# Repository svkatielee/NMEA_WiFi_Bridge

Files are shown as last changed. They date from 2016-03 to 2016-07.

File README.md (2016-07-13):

# NMEA_WiFi_Bridge
An ESP8266-01 WiFi module to read NMEA serial data and UDP broadcast it to multiple openCPN instances as a Bridge.

<b>Update: This code has been tested with Arduino IDE rev 1.6.9 and ESP8266 addin of 2.1.0. Newer compilers fail.</b>

<b>Warning: A work in progress</b>

I want to be able to run openCPN on both a laptop and a tablet at the same time. I would like the laptop down below deck, safe from the rain and salt water spray. I would like to have a mostly waterproof tablet in the cockpit to monitor progress. And I would like to be able to quickly check the ship's status from the captain's berth when off watch, maybe on a smart phone.

The plan is to implement a device to read the serial data from all the boat instruments and send that data to openCPN over a WiFI link so there are no physical wires attached. It will broadcast the data with UDP so that multiple devices can read the data at the same time.

The ESP8266 ESP-01 was chosen because it was on hand and it has adequate I/O for this project.

The rs-232 input signal voltage should work with -12 to +12 volts. It was tested with a Garmin 72H which puts out -5 to +5.

<h3>Setup</h3>
Connect power and input signal rs-232 line with ground.
Press and hold config button, press reset, 
     continue to hold config until the LED stays lit.
Connect to the AP "NMEA WiFi Bridge" with a system/phone/etc.
Connect your brower to 10.1.1.1 with password in code "nmeawifi".`
Configure the form for your network and click the "configure" button.
Verify the results page.
Press reset or cycle power for the module to connect to your network.

To verify it is working, there is a status page on the address on the NMEA WiFi Bridge. Type this address into your browser.

<h3>Credits</h3>
The ESP was programmed with the Arduino IDE for ESP 1.6.5 and the board manager version 1.6.5-947-g39819f0.

Also uses the pfodWebWiFiConfig and adapted schematic from http://www.forward.com.au/pfod/CheapWifiShield/ESP2866_01_WiFi_Shield/ESP8266_01_WiFi_Shield_R1/index.html for the dynamic web config of the ESP.

I used the version 1.9 of the library pfodWifiConfig.zip which is now included as Doc/pfodWifiConfig.zip

<quote>
/**
 *  Cheap and Simple Wifi Shield for Arduino and other micros
 * http://www.forward.com.au/pfod/CheapWifiSheild/index.html
 *
 * (c)2015 Forward Computing and Control Pty. Ltd.
 * This code may be freely used for both private and commerical use.
 * Provide this copyright is maintained.
 */
</quote>

Follow his instructions for setting up the library from above. 
(Also copied here from http://www.forward.com.au/ for the verison I used)

---------------------------
<quote>
<h4>Programming the WiFi Shield</h4>

The WiFi Shield needs to be programmed once, only, and never again, with the web page configuration and the Serial to WiFi Bridge code.

To program the shield follow the instructions given on https://github.com/esp8266/Arduino under Installing With Boards Manager. When opening the Boards Manager from the Tools → Board menu and select Type Contributed and install the esp8266 platform. This project was compiled using the ESP8266 version 1.6.4-673-g8cd3697. Later versions well be better but may have their own bugs as the platform is evolving rapidly.

Close and re-open the Arduino IDE and you can now select “Generic ESP8266 Module” from Tools → Board menu.

You also need to install the latest version of pfodWifiConfig.zip which handles the storing and retrieval of the settings in EEPROM

a) Download this pfodWifiConfig.zip file to your computer, move it to your desktop or some other folder you can easily find<br>
b) Then use Arduino 1.6.5 IDE menu option Sketch → Import Library → Add Library to install it.<br>
(If Arduino does not let you install it because the library already exists then find and delete the older pfodWifiConfig folder and then import this one)<br>
c) Stop and restart the Arduino IDE and under File->Examples you should now see pfodWifiConfig.<br>
</quote>
---------------------------

Also borrowed from http://www.scienceprog.com/alternatives-of-max232-in-low-budget-projects/ for the rs-232 to ttl translation for the input pin.

And last but not least some programming concepts from https://github.com/wa0uwh/ERB-EspWebServer.

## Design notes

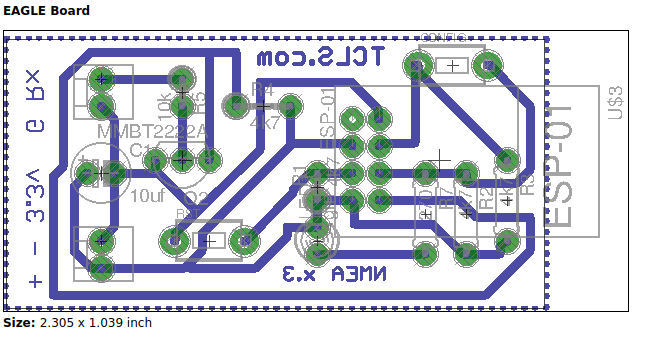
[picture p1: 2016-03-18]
eagle/NMEA_WiFi_Bridge_brd.png

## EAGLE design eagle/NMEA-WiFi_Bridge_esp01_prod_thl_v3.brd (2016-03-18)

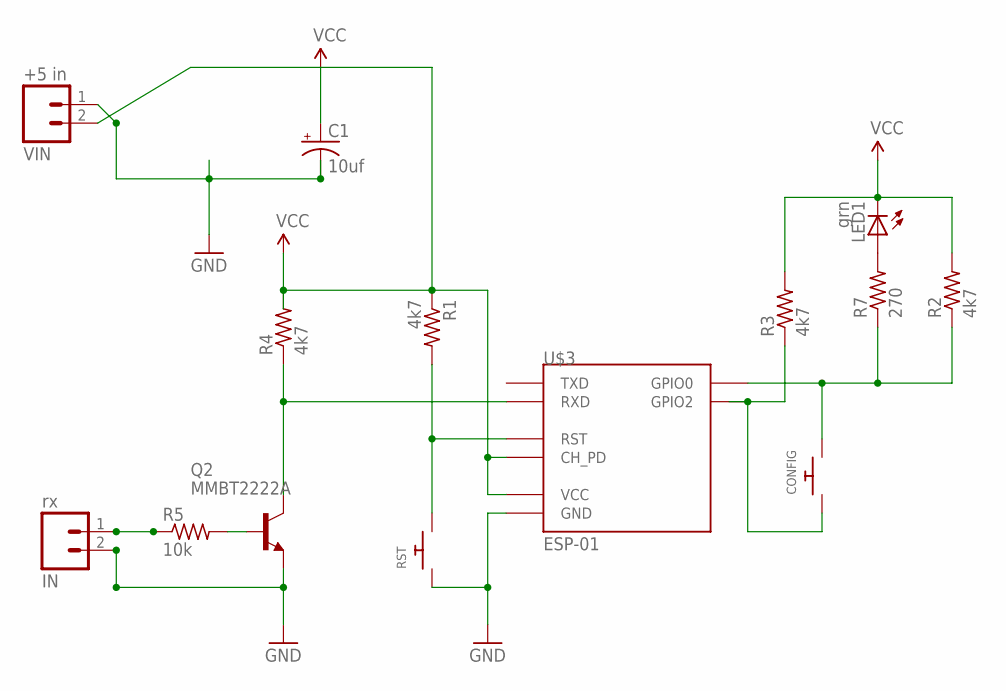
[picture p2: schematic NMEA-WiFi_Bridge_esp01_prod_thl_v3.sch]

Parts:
C1: 10uf; E2,5-6
CONFIG: SWITCH_PUSHBUTTONEVQ-PE; TACT_PANA-EVQ
IN: rx; MOLEX-1X2
LED1: grn; LED3MM
Q2: MMBT2222A; TO92-CBE
R1: 4k7; 0207/2V
R2, R3: 4k7; 0207/7
R4: 4k7; 0207/5V
R5: 10k; 0207/2V
R7: 270; 0207/7
RST: SWITCH_PUSHBUTTONEVQ-PE; TACT_PANA-EVQ
U$3: ESP-01
VIN: +5 in; MOLEX-1X2

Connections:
GND: C1.-, IN.2, Q2.E, RST.P$1, U$3.GND, VIN.1
GPIO0: CONFIG.P$2, R2.1, R7.1, U$3.GPIO0
unnamed: CONFIG.P$1, R3.1, U$3.GPIO2
unnamed: Q2.B, R5.2
unnamed: IN.1, R5.1
unnamed: LED1.A, R7.2
RST: R1.2, RST.P$2, U$3.RST
RX: Q2.C, R4.1, U$3.RX (RXD)
VCC: C1.+, LED1.K (C), R1.1, R2.2, R3.2, R4.2, U$3.CH_PD, U$3.VCC, VIN.2

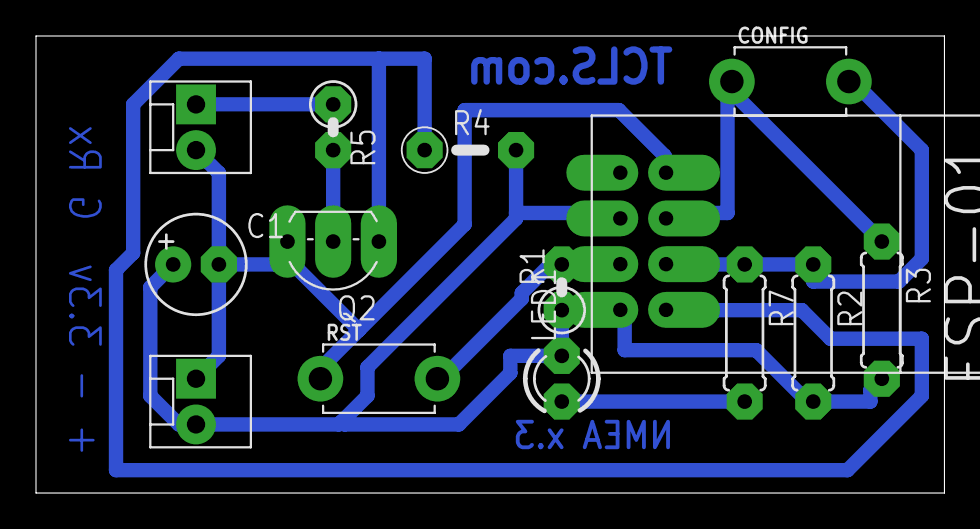
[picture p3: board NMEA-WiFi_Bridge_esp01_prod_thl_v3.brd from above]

Board: 2 copper layers, 50.5 x 25.4 mm, 14 parts (0 on the bottom side), 9 nets.

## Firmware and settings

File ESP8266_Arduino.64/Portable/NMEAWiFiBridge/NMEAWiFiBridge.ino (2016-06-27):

/*

   Copyright (c) Sept 8-2015. @ Larry Littlefield TCLS.com kb7kmo.blogspot.com
   GPL v2 
   https://github.com/svkatielee/

   
   Serial Wifi Bridge
   
   The desired purpose of this program is to take an rs-232 data stream and send it via 
   a UDP network protocol via WiFi to openCPN eleminating any data wires to the navagation system.
   Planning for a boat with a single network, the UDP is sent to the broadcast address
   of your network. ie.: 192.168.xx.255:10110

   Configure multiple openCPN systems connections, each with: network:UDP:localhost(0.0.0.0):10110 
   my testing with no checksum, no filtering at 4800 baud input
   
   It is written for an ESP8266-01 on a board similar to:
   http://www.forward.com.au/pfod/CheapWifiShield/ESP2866_01_WiFi_Shield/ESP8266_01_WiFi_Shield_R1/index.html

   It expects a NMEA 0183 rs-232 data stream input on the in pin connected to RX 
   via a 2N2222 to convert and invert -3.3v-+3.3v into 0-3.3v
   as seen: http://www.scienceprog.com/alternatives-of-max232-in-low-budget-projects/

   And some code and concepts borrowed from a friend, https://github.com/wa0uwh/ERB-EspWebServer

*/

 /**
 *  Cheap and Simple Wifi Shield for Arduino and other micros
 * http://www.forward.com.au/pfod/CheapWifiSheild/index.html
 *
 * (c)2015 Forward Computing and Control Pty. Ltd.
 * This code may be freely used for both private and commerical use.
 * Provide this copyright is maintained.
 */
 
#include <EEPROM.h>
#include <ESP8266WiFi.h>
#include <WiFiUdp.h>
#include <WiFiClient.h>
#include <ESP8266WebServer.h>
#include "pfodWifiConfig.h"

extern "C" {
    #include "user_interface.h"
    uint16 readvdd33(void);
}

#define DEBUG
#define Rev "LGL.00.06"
// ERB - Force format stings and string constants into FLASH Memory
    #define sF(x) (String) F(x)                // Used as an F() is being used as the first Element of a Multi-Element Expression
    #define FMT(x) strcpy_P(gFmtBuf, PSTR(x))  // Used with printf() for the format string
    // USE WITH CAUTION !
char gFmtBuf[64+2];



WiFiServer server(80);
WiFiClient client;
WiFiUDP udp;
pfodWifiConfig pfodWifiConfig;

// =============== start of pfodWifiWebConfig settings ==============
//#define pfodWifiWebConfigAP "WiFiBridge"
//#define pfodWifiWebConfigPASSWORD "lgl"
String pfodWifiWebConfigAP = "NMEA WiFi Bridge";
String pfodWifiWebConfigPASSWORD = "nmeawifi";


// note pfodSecurity uses 19 bytes of eeprom usually starting from 0 so
// start the eeprom address from 20 for configureWifiConfig
int eepromAddress = 20;
int wifiSetup_pin = 2; // name the input pin for setup mode detection GPIO2 on most ESP8266 boards
// =============== end of pfodWifiWebConfig settings ==============

// On ESP8266-01 and Adafruit HAZZAH ESP8266, connect LED + 270ohm resistor from D0 (GPIO0) to +3V3 to indicate when in config mode

char ssid[pfodWifiConfig::MAX_SSID_LEN + 1]; // allow for null  field 1
char security[pfodWifiConfig::MAX_SECURITY_LEN + 1]; // field 2
char password[pfodWifiConfig::MAX_PASSWORD_LEN + 1]; // field 3
char portNo[pfodWifiConfig::MAX_PORTNO_STR_LEN + 1]; // field 4
char staticIP[pfodWifiConfig::MAX_STATICIP_LEN + 1]; // field 5 use dhcp if empty
char hostName[pfodWifiConfig::MAX_HOSTNAME_LEN + 1]; // field 6
char userName[pfodWifiConfig::MAX_USERNAME_LEN + 1]; // field 7
char userPw[pfodWifiConfig::MAX_USER_PASSWORD_LEN + 1]; // field 8


uint16_t ipSources = pfodFeatures::DHCP | pfodFeatures::STATIC_IP; // bit or these together pfodFeatures::DHCP|pfodFeatures::STATIC_IP if both are available
uint16_t securityFeatures = pfodFeatures::WPA | pfodFeatures::WPA2; // bit or these together e.g. pfodFeatures::OPEN | pfodFeatures::WPA

ESP8266WebServer webserver ( 80 );  // this just sets portNo nothing else happens until begin() is called

String msg;
byte inConfigMode = 0; // false

IPAddress opencpnServer;          // openCPN system server network broadcast
unsigned int localPort = 2948;    // local port to listen for UDP packets only needed for startup
unsigned int cpnPort;             // remote port to send UDP packets
unsigned int baudRate;            // set serial baud for reading NMEA (stored as hostName)

const byte maxLen = 100;          // longest NMEA sentence
byte packetBuffer[maxLen];        // buffer for UDP communication
int len=0;                        // num chars in buffer
boolean stringComplete = false;   // whether the string is complete
#ifdef DEBUG 
int loop_count=1;                 // show progress in debug window
#endif
uint16_t udpPackSent=0;           // the number of UDP packets sent

char gTmpBuf[32+2];  // Generic Temp Buffer


//*******************************************************************
//===================================================================
void setup() {
  delay(2000); // skip the ESP8266 booting debug output
  pinMode(0,OUTPUT); // make GPIO0 an output
  digitalWrite(0,LOW); // make it LOW so it will ground GPIO2 if CONFIG_LINK is shorted out.
  // will turn led on, if any connected
  WiFi.mode(WIFI_STA);
  inConfigMode = 0; // non in config mode
  EEPROM.begin(512);
  
  Serial.begin(4800);
  delay(10);     // wait for serial to connect
  Serial.println();
  

pfodWifiConfig.setDebugStream(&Serial); // add this line if using DEBUG in pfodWifiConfig_ESP8266 library code

  //============ pfodWifiConfigV1 config in Access Point mode ====================
  // see if config button is pressed
  pinMode(wifiSetup_pin, INPUT_PULLUP);
  if (digitalRead(wifiSetup_pin) == LOW) {
    inConfigMode = 1; // in config mode
    WiFi.mode(WIFI_AP_STA);

#ifdef DEBUG
    Serial.println(F("Setting up Access Point for pfodWifiWebConfig"));
    Serial.print("AP: ");
    Serial.print(pfodWifiWebConfigAP);
    Serial.print(" Pw: ");
    Serial.println( pfodWifiWebConfigPASSWORD);
#endif
    // connect to temporary wifi network for setup
    // the features determine the format of the {set...} command
    setupAP(pfodWifiWebConfigAP, pfodWifiWebConfigPASSWORD);
    //   Need to reboot afterwards
    return; // skip rest of setup();
  }  
//============ end pfodWifiConfigV1 config ====================

  // else button was not pressed continue to load the stored network settings
  // make GPIO0 an input to turn led off when not in config mode, if any is connected
  pinMode(0,INPUT);

    // use these local vars
  char ssid[pfodWifiConfig::MAX_SSID_LEN + 1]; // allow for null
  char password[pfodWifiConfig::MAX_PASSWORD_LEN + 1];
  char staticIP[pfodWifiConfig::MAX_STATICIP_LEN + 1];
  char hostName[pfodWifiConfig::MAX_HOSTNAME_LEN + 1]; // use for Serial in baud rate
  uint16_t portNo = 0; // use for UDP portnumber cpnPort
  uint16_t security = 0;
  uint16_t ipSource = 0;
  byte mode = 0;

  pfodWifiConfig.loadNetworkConfigFromEEPROM(eepromAddress, &mode,
      (char*)ssid, pfodWifiConfig::MAX_SSID_LEN + 1, (char*)password,  pfodWifiConfig::MAX_PASSWORD_LEN + 1,
      &security, &portNo, &ipSource, (char*)staticIP,  pfodWifiConfig::MAX_STATICIP_LEN + 1);
  pfodWifiConfig.loadClientConfigFromEEPROM(eepromAddress, (char*)hostName, pfodWifiConfig::MAX_HOSTNAME_LEN, (char*)userName,
      pfodWifiConfig::MAX_USERNAME_LEN, (char*)userPw, pfodWifiConfig::MAX_USER_PASSWORD_LEN);

  // Use hostName for storing the baud rate for the NMEA input
  long longBaud = 0;
      pfodWifiConfig::parseLong((byte*)hostName, &longBaud);
      baudRate = (uint16_t)longBaud;

  Serial.begin(baudRate);
  server = WiFiServer(80);
  cpnPort = portNo;
  // Initialise wifi module
#ifdef DEBUG
  Serial.println(F("Normal boot"));
  Serial.print("Web server on port:"); Serial.println(80);
  Serial.println(F("Connecting to AP"));
  Serial.print("ssid '");
  Serial.print(ssid);
  Serial.println("'");
  Serial.print("password '");
  Serial.print(password);
  Serial.println("'");
#endif
  // Blink LED while trying to connect to WiFi
  pinMode(0,OUTPUT); // make GPIO0 an output
  int blink0 = 0;
  digitalWrite(0,blink0);
  WiFi.begin(ssid, password);
  while (WiFi.status() != WL_CONNECTED) {
    blink0 = ! blink0;
    digitalWrite(0,blink0);
    delay(500);
#ifdef DEBUG
    Serial.print(".");
#endif
  }
  digitalWrite(0, HIGH);  // finished using LED for connecting status
  pinMode(0,INPUT);
#ifdef DEBUG
  Serial.println();
  Serial.println(F("Connected!"));
#endif

  if (*staticIP != '\0') {
    // config static IP
    IPAddress ip(pfodWifiConfig::ipStrToNum(staticIP));
    IPAddress gateway(ip[0], ip[1], ip[2], 1); // set gatway to ... 1
#ifdef DEBUG
    Serial.print(F("Setting gateway to: "));
    Serial.println(gateway);
#endif
    IPAddress subnet(255, 255, 255, 0);
    WiFi.config(ip, gateway, subnet);
  } // else leave as DHCP


  // configure normal boot web server
  webserver.on ( "/", handleRootNormal );
  webserver.onNotFound ( handleNotFound );
  
  // Start listening for connections
#ifdef DEBUG
  Serial.println(F("Start Server"));
#endif
  webserver.begin();
  
  opencpnServer = WiFi.localIP(); // find my local IP address
  opencpnServer[3] = 255;         // Set last octet to 255 for Class C broadcast address of this subnet
  
#ifdef DEBUG
  Serial.println(F("Server Started"));
  // Print the IP address
  Serial.print(WiFi.localIP());
  Serial.print(':');
  Serial.println(80);
  Serial.println(F("Listening for connections..."));
  Serial.print("UDP send address: ");
  Serial.print(opencpnServer);
  Serial.print(":");
  Serial.println(cpnPort);
#endif

#ifdef DEBUG
  Serial.println("Starting UDP");
#endif
  udp.begin(localPort);
#ifdef DEBUG 
  Serial.print("Local port: ");
  Serial.println(udp.localPort());
#endif

#ifdef DEBUG
  Serial.println("+++"); // end of setup
#endif

}  // setup

//===================================================================
void setupAP( String ssid_wifi,  String password_wifi) {
  const char *aps = scanForAPs();
  delay(0);
#ifdef DEBUG
  Serial.println(aps);
#endif

  IPAddress local_ip = IPAddress(10, 1, 1, 1);
  IPAddress gateway_ip = IPAddress(10, 1, 1, 1);
  IPAddress subnet_ip = IPAddress(255, 255, 255, 0);

#ifdef DEBUG
  Serial.println(F("configure pfodWifiWebConfig"));
  Serial.print("AP: ");
  Serial.print(ssid_wifi);
  Serial.print(" Pw: ");
  Serial.println( password_wifi);
#endif

  WiFi.softAP(ssid_wifi.c_str(), password_wifi.c_str(), 6);
  //WiFi.softAP(ssid_wifi, 0, 6);

#ifdef DEBUG
  Serial.println();
  Serial.println(F("Access Point setup"));
#endif
  WiFi.softAPConfig(local_ip, gateway_ip, subnet_ip);

#ifdef DEBUG
  Serial.println("done");
  IPAddress myIP = WiFi.softAPIP();
  Serial.print(F("My address: "));
  Serial.println(myIP);
#endif


  msg = "<html>"
        "<head>"
        "<title>Serial to Wifi Bridge Setup</title>"
        "<meta charset=\"utf-8\" />"
        "<meta name=viewport content=\"width=device-width, initial-scale=1\">"
        "</head>"
        "<body>"
        "<h2>Serial to Wifi Bridge Setup</h2>"
        "<p>Use this form to configure this device to connect to your Wifi network and start as a Status server listening"
        " on port 80. Also configure the port that the NMEA data will be broadcast via UDP. And the baud rate for the NMEA data.</p>"
        "<p>Note: UDP packets will be sent to the broadcast IP of your class C network. ie.: nnn.nnn.nnn.255</P>"

        "<form class=\"form\" method=\"post\" action=\"/config\" >"
        "<p class=\"name\">"
        "<label for=\"name\">Network SSID</label><br>"
        "<input type=\"text\" name=\"1\" id=\"ssid\" placeholder=\"wifi network name\"  required "; // field 1

  if (*aps != '\0') {
    msg += " value=\"";
    msg += aps;
    msg += "\" ";
  }
  msg += " />"
         "</p> "
         "<p class=\"security\">"
         "<label for=\"security\">Security</label><br>"
         "<select name=\"2\" id=\"security\" required>" // field 2
         "<option value=\"WPA/WPA2\">WPA/WPA2</option>"
         "</select>"
         "</p>"
         "<p class=\"password\">"
         "<label for=\"password\">Password</label><br>"
         "<input type=\"text\" name=\"3\" id=\"password\" placeholder=\"wifi network password\" autocomplete=\"off\" required " // field 3
         "</p>"
         "<p class=\"static_ip\">"
         "<label for=\"static_ip\">Set the Static IP for this device</label><br>"
         "(If this field is empty, DHCP will be used to get an IP address)<br>"
         "<input type=\"text\" name=\"5\" id=\"static_ip\" placeholder=\"192.168.4.99\" "  // field 5
         " pattern=\"\\b(?:(?:25[0-5]|2[0-4][0-9]|[01]?[0-9][0-9]?)\\.){3}(?:25[0-5]|2[0-4][0-9]|[01]?[0-9][0-9]?)\\b\"/>"
         "</p>"
         "<p class=\"portNo\">"
         "<label for=\"portNo\">UDP broadcast port.</label><br>"
         "<input type=\"text\" name=\"4\" id=\"portNo\" placeholder=\"10110\" required"  // field 4
         " pattern=\"\\b([0-9]{1,4}|[1-5][0-9]{4}|6[0-4][0-9]{3}|65[0-4][0-9]{2}|655[0-2][0-9]|6553[0-5])\\b\" />"
         "</p>"
         "<p class=\"hostName\">"
         "<label for=\"hostName\">Baud rate for NMEA serial line.</label><br>"
        //"<input type=\"text\" name=\"6\" id=\"hostName\" placeholder=\"38400\" required"  // field 6
         "<select name=\"6\" id=\"hostName\" required>" // field 6 was hostName, using for Baud
         "<option value=\"4800\">4800</option>"
         "<option value=\"9600\">9600</option>"
         "<option value=\"38400\" selected>38400</option>"
         "<option value=\"115200\">115200</option>"
         "</select>"
         "</p>"
"<p class=\"submit\">"
         "<input type=\"submit\" value=\"Configure\"  />"
         "</p>"
         "</form>"
         "</body>"
         "</html>";


  delay(100);

  webserver.on ( "/", handleRoot );
  webserver.on ( "/config", handleConfig );
  webserver.onNotFound ( handleNotFound );
  webserver.begin();
#ifdef DEBUG
  Serial.println ( "HTTP webserver started" );
#endif
}  //end of setupAp



//********************************************************
// not really event driven serial input
void serialEvent() {
  while (Serial.available()) {
    // get the new byte:
    packetBuffer[len] = (char)Serial.read();
    // if the incoming character is a newline, set a flag
    // so the main loop can do something about it:
    if (packetBuffer[len] == '\n') {
      stringComplete = true;
    }
    yield();
    len++;
    if (len > maxLen) {    // if we missed the newline don't oveer run the buffer
      sendUDPpacket(opencpnServer); 
      len=0;
#ifdef DEBUG  
    Serial.println("maxLen exceeded");
#endif  
    }
  }
}


//********************************************************
// send the unidirectional UDP buffer to the specific address and preconfigured port
unsigned long sendUDPpacket(IPAddress& address)
{
#ifdef DEBUG 
  Serial.print("sending NTP packet=");
  Serial.println(len); 
#endif  
  udp.beginPacket(address, cpnPort); 
  udp.write(packetBuffer, len);
  udp.endPacket();
  udpPackSent++;
}



//*******************************************************************
//===================================================================
void loop() {
  if (inConfigMode) {
    webserver.handleClient();
    delay(0);
    return;
  } 
  delay(10);

#ifdef DEBUG 
  loop_count++;
  if ((loop_count % 10) == 0) Serial.print(".");
  if ((loop_count % 1000) == 0) Serial.println("!");
#endif  

  serialEvent();          // check for more NMEA data
  yield();
  if (stringComplete) {   // have a whole NMEA sentence?
    sendUDPpacket(opencpnServer); 
    len=0;
    stringComplete = false; 
  }
  yield();

  webserver.handleClient();  // check if client wants a webpage
  yield();
}

// ###########################################################
//////////////////////////////////////////////////////////////
//
// Provides UpTime in Seconds
//
unsigned long
upTime()
{
  return millis() / 1000;
}


//==============================================================================
String upTimeStr()
{
//    char buf[PBUFSIZE];
    
    int uptimesec = upTime();
    int uptimemin = uptimesec / 60;
    int uptimehr  = uptimemin / 60;
    int uptimeday = uptimehr  / 24;
    yield();

    uptimesec %= 60;
    uptimemin %= 60;
    uptimehr  %= 24;

    snprintf( gTmpBuf, sizeof(gTmpBuf),
        FMT("%d Days, %02d:%02d:%02d"), uptimeday, uptimehr, uptimemin, uptimesec );
    yield();
    
    return gTmpBuf;
} 



//==============================================================================
const size_t MAX_SSID_LEN = 32;
char ssid_found[MAX_SSID_LEN + 1]; // max 32 chars + null

// will always put '\0\ at dest[maxLen]
// return the number of char copied excluding the terminating null
size_t strncpy_safe(char* dest, const char* src, size_t maxLen) {
  size_t rtn = 0;
  if (src == NULL) {
    dest[0] = '\0';
  } else {
    strncpy(dest, src, maxLen);
    rtn = strlen(src);
    if ( rtn > maxLen) {
      rtn = maxLen;
    }
  }
  dest[maxLen] = '\0';
  return rtn;
}


//==============================================================================
const char* scanForAPs() {
  // WiFi.scanNetworks will return the number of networks found
  int8_t n = WiFi.scanNetworks();
#ifdef DEBUG
  Serial.print ("Scan done\n");
#endif
  delay(0);
  int32_t maxRSSI = -1000;
  strncpy_safe((char*)ssid_found, "", MAX_SSID_LEN); // empty
  if (n <= 0) {
#ifdef DEBUG
    Serial.print("No networks found\n");
#endif
  } else {
#ifdef DEBUG
    Serial.print("Networks found:");
    Serial.println(n);
#endif
    for (int8_t i = 0; i < n; ++i) {
      String ssid_scan = WiFi.SSID(i);
      int32_t rssi_scan = WiFi.RSSI(i);
      uint8_t sec_scan = WiFi.encryptionType(i);
      if (rssi_scan > maxRSSI) {
        maxRSSI = rssi_scan;
        strncpy_safe((char*)ssid_found, ssid_scan.c_str(), MAX_SSID_LEN);
      }
#ifdef DEBUG
      Serial.print(ssid_scan);
      Serial.print(" ");
      Serial.print(encryptionTypeToStr(sec_scan));
      Serial.print(" ");
      Serial.println(rssi_scan);
#endif

      delay(0);
    }
  }
  return ssid_found;
}

//==============================================================================
void handleRoot() {                  
  webserver.send ( 200, "text/html", msg );
}
 
//==============================================================================
void handleRootNormal() {     

  msg = "<!DOCTYPE html>"
        "<html>"
        "<head>"
        "<title>NMEA to Wifi Bridge</title>"
        "<meta http-equiv=\"refresh\" content=\"10\" />"
        "<meta charset=\"utf-8\" />"
        "<meta name=viewport content=\"width=device-width, initial-scale=1\">"
        "<meta http-equiv='Pragma' content='no-cache'>"
        "<link rel='shortcut icon' href='http://espressif.com/favicon.ico'>"
        "<style>"
        "  body {background-color: #ddddee;}"
        "</style> "
        "</head>"
        "<body>"
        "<center>"
        "<h1>Serial to Wifi Bridge</h1>"
        "<p>This device broadcasts the input <br>"
        "NMEA data stream to your Wifi network.</p>"
        "<p>Configure multiple openCPN <br>"
        "systems\' connections, each with: <br>"
        "Properties   <b>network</b><br>"
        "Protocol <b>UDP</b><br>"
        "Address <b>localhost</b><br>"
        "DataPort <b>" + String((int)cpnPort) + "</b></p>"
        "<br>";
        
  msg += "    UDP to: <b>" + String(opencpnServer[0]) + "." + String(opencpnServer[1])
                     + "." + String(opencpnServer[2]) + "." + String(opencpnServer[3]);
  msg += ":" + String((int)cpnPort) + F("</b><br>");
  yield();
  msg += "    UDP packets sent: <b>" + String(udpPackSent) + F("</b><br>");
  msg += "    Uptime: <b>"          + String(upTimeStr()) + F("</b><br>");
  msg += "    Batt Voltage: <b>"    + String(readvdd33()/1000.0, 2) + F("V</b><br>");
 // msg += "    My IPA: <b>"fddd5819         + String(server.client().remoteIP()) + F("</b><br>");

  msg += "<br><br>To reconfigure, press and hold config button, press reset, "
         "continue to hold config until the yellow LED stays lit.<br>";
  msg += "<br>Revision: " + String(Rev) +  "<br>";
  msg += F("Powered by: <a href='http://espressif.com/'>Esp8266</a>");
  
  msg += "</center>"
         "</body>"
         "</html>";
  yield();      
#ifdef DEBUG
  Serial.print ("in handleRootNormal\n");
#endif                                        
  webserver.send ( 200, "text/html", msg );
}
//==============================================================================
void handleNotFound() {
  String message = "File Not Found\n\n";
  message += "URI: ";
  message += webserver.uri();
  message += "\nMethod: ";
  message += ( webserver.method() == HTTP_GET ) ? "GET" : "POST";
  message += "\nArguments: ";
  message += webserver.args();
  message += "\n";

  for ( uint8_t i = 0; i < webserver.args(); i++ ) {
    message += " " + webserver.argName ( i ) + ": " + webserver.arg ( i ) + "\n";
  }

  webserver.send ( 404, "text/plain", message );
}

//==============================================================================
void handleConfig() {
  ssid[0] = '\0';  // field 1
  security[0] = '\0'; // field 2 this field skipped always WPA-WPA2
  password[0] = '\0'; // field 3
  portNo[0] = '\0'; // field 4
  staticIP[0] = '\0'; // field 5
  hostName[0] = '\0'; // field 6
  userName[0] = '\0'; // field 7
  userPw[0] = '\0'; // field 8
  uint16_t portNoInt = 80; // default

  byte mode = pfodFeatures::SERVER;
  uint16_t securityMode = pfodFeatures::WPA_WPA2;
  uint16_t portNo = 80;
  uint16_t ipSource = 0;
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

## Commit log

2015-09-13 Rev LGL.00.04 initial commit
    [NMEA_WiFi_Bridge.fzz]
2015-10-18 Add blink LED while connecting to SSID
2016-03-18 add eagle files sch brd version 0.3
    [NMEA-WiFi_Bridge_esp01_prod_thl_v3.brd, NMEA-WiFi_Bridge_esp01_prod_thl_v3.sch]
2016-06-27 fixed const char* error
    [NMEAWiFiBridge.ino]

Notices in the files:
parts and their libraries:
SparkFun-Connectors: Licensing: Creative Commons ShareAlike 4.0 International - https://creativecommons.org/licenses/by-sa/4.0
